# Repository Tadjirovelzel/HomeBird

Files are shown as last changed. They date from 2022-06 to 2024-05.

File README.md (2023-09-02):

The project NestWacht in collaboration with the TU Delft and other benefactors aims to design a sensor station in the form of a birdhouse that uses a camera and weather sensors to document bird activity and monitor properties of the local atmosphere such as humidity, pressure and particulate matter levels. 
This file serves to outline the structure and purpose of the folders contained within the project.

# Project Structure
The essential project structure is displayed below:

    -Code
        -arduino_firmware
        -esp_firmware
        -test_camera
        -test_video
        -legacy_code
    -Enclosure
    -Kicad
        -main_board
        -camera_board
        -gerbers

    The project also contains the complete material bill and the login information for the Node Developer platform.
    Some irrelevant and older development code is stored in the legacy_code folder. 

The electronical components were initally designed by Maarten van Schagen and Quinten Luyten. Tadjiro Velzel further implemented the design and attempted to correct inital mistakes.
The programming necessary to ensure correct and smooth operation of the board and the server was done by Lennard Duynkerke.
The enclosure of the electronics was designed by Thomas van Leeuwen.
The project was overseen and managed by Marit Bogert and Teun Verkerk.

# Hardware
The main board contains the following components, split into sections.

    Power systems section:
        - Three battery connector footprints that lead to battery holders containing three 16650 LiOn batteries
        - Three TP4056 battery charger modules
        - A Solar charger footprint leading to a solar panel
        - A boost converter that regulates the battery power to 5V
        - A Diode to route solar power directly to the boost converter
        - A Diode to regulate the arduino's ability to turn off the boost converter, thus turning off the Esp32 and particulate matter sensor
        - A power FET which turns off the Esp32 and Particulate matter sensor
        - Resistors to regulate the power throughput towards the FET

    Computative section:
        - An Arduino Every that drives the power towards the ESP32 and operates the sensors and an SD card to store sensor data.
        - A LilyGo ESP32 development board

    Sensoric section:
        - Two BME280 breakout boards to monitor air pressure, humidity and temperature both within the birdhouse and towards the outside air
        - A PMS5003 particulate matter sensor

    Data transfer:
        - A Sim LTE module (LilyGo SIM7600E) for data transfer
        - An LTE antenna to transfer data over LTE
        - A Sim-card to route information accross the internet
        - An SD card that stores the sensor data before sending it

The Camera Board contains the following components:

    - An OV2640 camera operating within the visible and infrared spectra 
    - A 24 pin camera connector, soldered to the board
    - A network of capacitors to smooth the voltages of the camera connector and voltage regulators
    - A 2.8V and 1.2V voltage regulator to supply the camera
    - A system of resistors to preload the camera
    - A motion sensor to detect bird activity and trigger the camera
    - Four infrared LEDs to light up for pictures at night, which the birds cannot sense
    - A larger resistor to regulate current to the infrared LEDs

To contain the electronics mentioned above, a plastic enclosure made, printed in PETG by 3d-printer. The design files for this are available in the enclosure folder.

# Software
The software is split in two parts: `arduino_firmware` and `esp_firmware`. The former is designed for the Arduino Every, the main computational unit which is always powered on and operates sensors, sd card, and power to the ESP32. The latter is ran on the LilyGo ESP32 and is used to communicate with the outer world over a 4G connection, as well as to take pictures with the OV2640 camera. Two test files are added in order to test a specific part of the software, `test_camera` to test the camera either over WiFi or over 4G and `test_video` to record an .avi video by sticking individual .jpg files together. For a more detailed description of the software one is directed to the headers of the individual .cpp files.

# Problems
Currently the project contains the following issues:
* Sim module will not send large pictures
* Camera init and capture is inconsistent, bound to inconsistency of the camera connector
* Pin assignment in code does not correspond to PCB design files: PCB files are incorrect and can never work: pin assignment in software is correct.
* Complete integration was never tested
* Likely complete system is too power intensive to drive by solar panel. (Also never tested fully)

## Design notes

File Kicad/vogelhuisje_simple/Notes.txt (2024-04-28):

Useful voltage regulator:
https://www.ti.com/lit/ds/symlink/lm3940.pdf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

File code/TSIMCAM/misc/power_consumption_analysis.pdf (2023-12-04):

### GPS: every 60 seconds, API: 1 point per payload

| mcu - simple delay module - on | mcu - sleep module - on | mcu - deep sleep module - on | mcu - simple delay module - low power mode | mcu - simple delay module - off
Power (mWh) | 286 | 196 | 187 | 298 | 530
Time (s) | 2110s | 1674s | 1544s | 1932s | 3453s
# GPS Points | 34 | 27 | 25 | 32 | 44

# API Posts | 34 | 27 | 25 | 32 | 44

Power (mWh) per hour | 487.962085308057 | 421.505376344086 | 436.010362694301 | 555.27950310559 | 552.562988705474
Power (mWh) per day | 11711.0900473934 | 10116.1290322581 | 10464.2487046632 | 13326.7080745342 | 13261.5117289314
Seconds Per GPS Point | 62s 59ms | 62s | 61s 760ms | 60s 375ms | 78s 477ms
Seconds Per Post | 62s 59ms | 62s | 61s 760ms | 60s 375ms | 78s 477ms
gps_refresh_period (ms) | 60000 | 60000 | 60000 | 60000 | 60000 | 60000 | 60000
api_num_gps_points_in_payload | 1 | 1 | 1 | 1 | 1 | 1 | 1
First Point in API | 03/11/2023 4:01:58 PM | 03/11/2023 4:39:57 PM | 03/11/2023 5:11:57 PM | 03/11/2023 5:41:22 PM | 03/11/2023 2:59:59 PM
Last Point in API | 03/11/2023 4:37:08 PM | 03/11/2023 5:07:51 PM | 03/11/2023 5:37:41 PM | 03/11/2023 6:13:34 PM | 03/11/2023 3:57:32 PM
| 2110s | 1674s | 1544s | 1932s | 3453s | 0 | 0

### GPS: 1min vs 10min per point, API: 1 point per payload

| mcu - simple delay module - on every 1min | mcu - simple delay module - on every 10min | mcu - simple delay module - low power mode every 1min | mcu - simple delay module - low power mode every 10min | mcu - simple delay module - off every 1min | mcu - simple delay module - off every 10min
Power (mWh) | 286 | 1586 | 298 | 2786 | 530 | 944
Time (s) | 2110s | 16309s | 1932s | 29021s | 3453s | 19957s
# GPS Points | 34 | 28 | 32 | 42 | 44 | 33

# API Posts | 34 | 28 | 32 | 42 | 44 | 33

Power (mWh) per hour | 487.962085308057 | 350.088907964927 | 555.27950310559 | 345.59801523035 | 552.562988705474 | 170.286115147567
Power (mWh) per day | 11711.0900473934 | 8402.13379115825 | 13326.7080745342 | 8294.3523655284 | 13261.5117289314 | 4086.86676354161
Seconds Per GPS Point | 62s 59ms | 582s 464ms | 60s 375ms | 690s 976ms | 78s 477ms | 604s 758ms
Seconds Per Post | 62s 59ms | 582s 464ms | 60s 375ms | 690s 976ms | 78s 477ms | 604s 758ms
gps_refresh_period (ms) | 60000 | 600000 | 60000 | 600000 | 60000 | 600000
api_num_gps_points_in_payload | 1 | 1 | 1 | 1 | 1 | 1
First Point in API | 03/11/2023 4:01:58 PM | 03/11/2023 6:32:56 PM | 03/11/2023 5:41:22 PM | 03/11/2023 11:09:26 PM | 03/11/2023 2:59:59 PM | 03/12/2023 7:16:28 AM
Last Point in API | 03/11/2023 4:37:08 PM | 03/11/2023 11:04:45 PM | 03/11/2023 6:13:34 PM | 03/12/2023 7:13:07 AM | 03/11/2023 3:57:32 PM | 03/12/2023 12:49:05 PM
| 2110s | 16309s | 1932s | 29021s | 3453s | 19957s

### GPS: 1min vs 10min per point, API: 1 point per payload

| mcu - deep sleep module - off every 1s | mcu - deep sleep module - off every 10min | mcu - deep sleep module - off every 20min | mcu - deep sleep module - off every 30min | mcu - deep sleep module - off every 40min | mcu - deep sleep module - off every 50min | mcu - deep sleep module - off every 60min
Power (mWh) | 173 | 346 | 560 | 298 | 367 | 530 | 1020
Time (s) | 949s | 10652s | 22382s | 0 | 17235s | 0 | 58249s
# GPS Points | 14 | 18 | 19 | 32 | 8 | 44 | 17

# API Posts | 14 | 18 | 19 | 32 | 8 | 44 | 17

Power (mWh) per hour | 656.269757639621 | 116.935786706722 | 90.0723795907426 | | 76.6579634464752 | | 63.0397088362032
Power (mWh) per day | 15750.4741833509 | 2806.45888096133 | 2161.73711017782 | | 1839.7911227154 | | 1512.95301206888
Seconds Per GPS Point | 73s | 626s 588ms | 1243s 444ms | 0 | 2462s 143ms | 0 | 3640s 563ms
Seconds Per Post | 73s | 626s 588ms | 1243s 444ms | 0 | 2462s 143ms | 0 | 3640s 563ms
Power (mWh) per point | 12.3571428571429 | 19.2222222222222 | 29.4736842105263 | 9.3125 | 45.875 | 12.0454545454545 | 60
gps_refresh_period (ms) | 1000 | 600000 | 1200000 | 180000 | 2400000 | 300000 | 3600000
api_num_gps_points_in_payload | 1 | 1 | 1 | 1 | 1 | 1 | 1
First Point in API | 03/14/2023 7:23:09 PM | 03/13/2023 2:20:58 PM | 03/13/2023 8:00:48 AM | | 03/14/2023 9:37:40 AM | | 03/13/2023 5:22:30 PM
Last Point in API | 03/14/2023 7:38:58 PM | 03/13/2023 5:18:30 PM | 03/13/2023 2:13:50 PM | | 03/14/2023 2:24:55 PM | | 03/14/2023 9:33:19 AM
| 949s | 10652s | 22382s | 0 | 17235s | 0 | 58249s
Notes | This is about as fast as the module can turn on and off. The MCU is not sleeping because the pre-nap and post-nap values are larger than the 1 second. | | | | | | This is heading towards the board limit of 0.0107A x 5.088V = 54.4mWh. The 0.0107A draw is when the module is off and the mcu is in deep sleep.

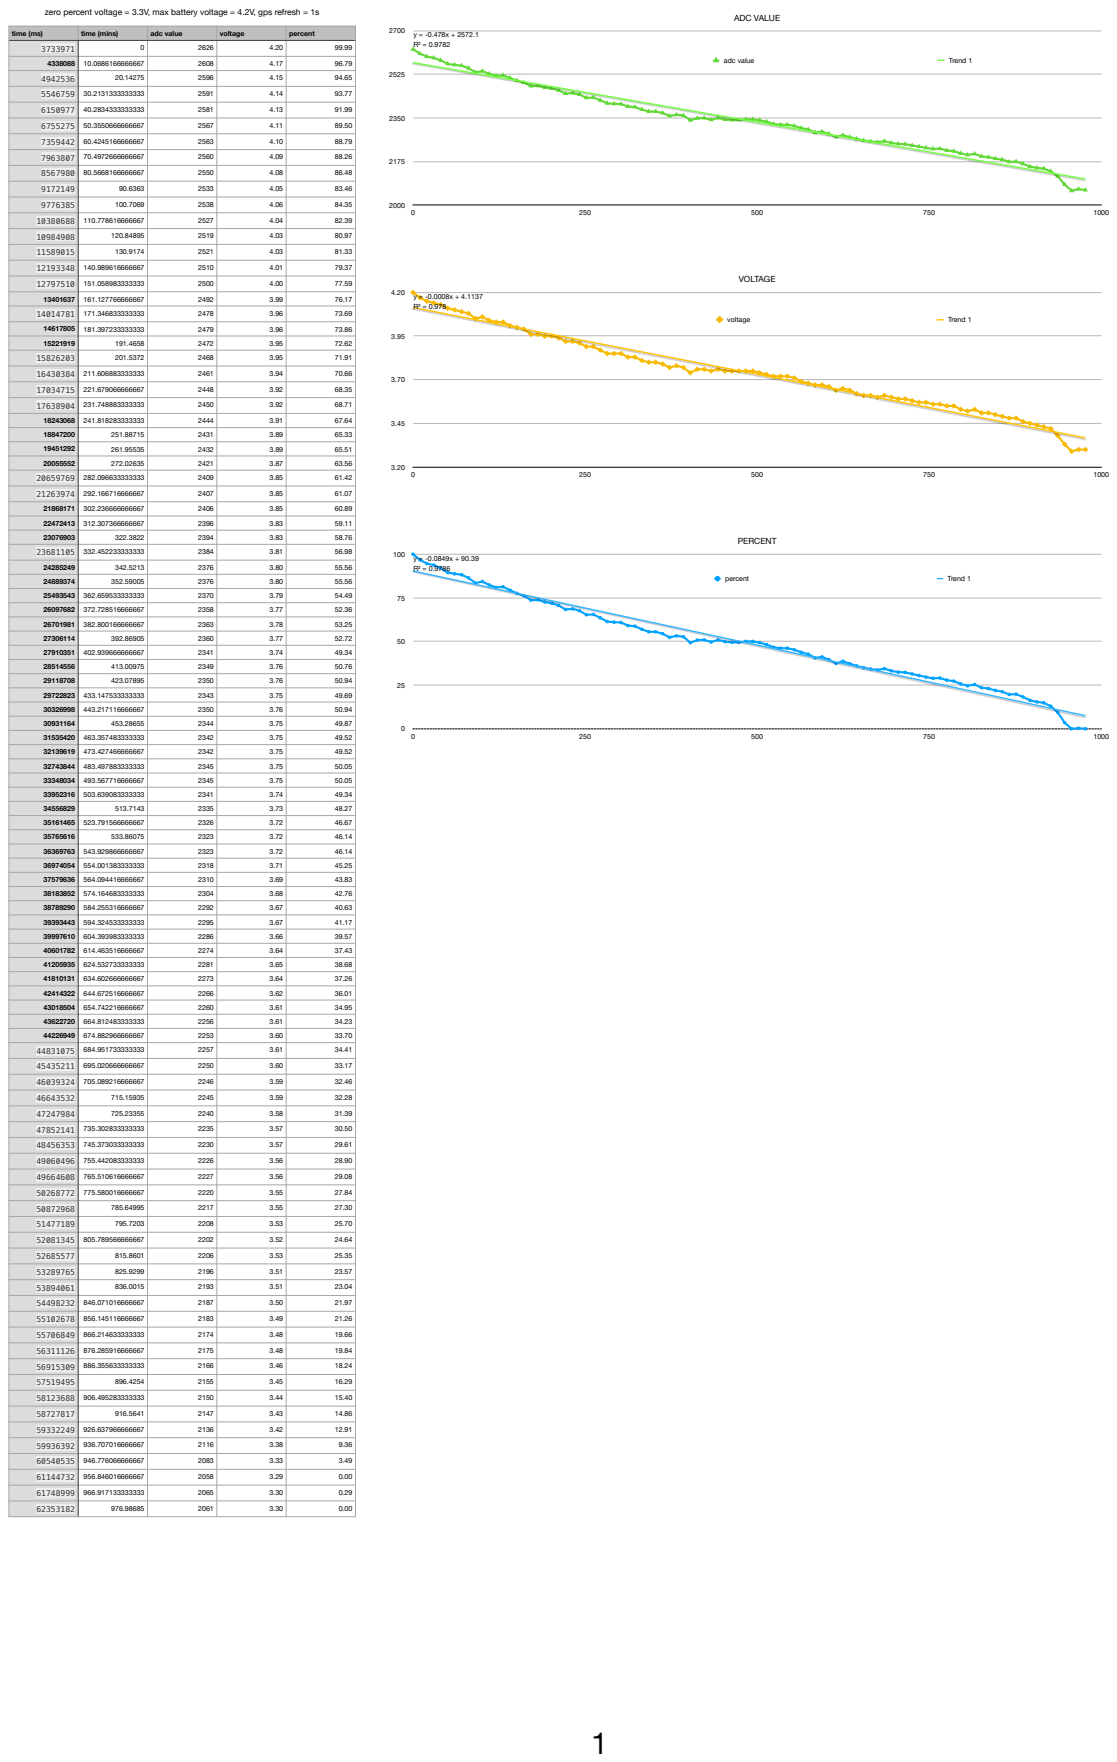
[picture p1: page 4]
PERCENT; percent; Trend 1; ADC VALUE; adc value; VOLTAGE; voltage

zero percent voltage = 3.3V, max battery voltage = 4.2V, gps refresh = 1s

time (ms) | time (mins) | adc value | voltage | percent

4338088 | 10.0686166666667 | 2608 | 4.17 | 96.79
4942536 | 20.14275 | 2596 | 4.15 | 94.65

13401637 | 161.127766666667 | 2492 | 3.99 | 76.17
14014781 | 171.346833333333 | 2478 | 3.96 | 73.69

14617805 | 181.397233333333 | 2479 | 3.96 | 73.86
15221919 | 191.4658 | 2472 | 3.95 | 72.62
15826203 | 201.5372 | 2468 | 3.95 | 71.91

18243068 | 241.818283333333 | 2444 | 3.91 | 67.64
18847200 | 251.88715 | 2431 | 3.89 | 65.33
19451292 | 261.95535 | 2432 | 3.89 | 65.51
20055552 | 272.02635 | 2421 | 3.87 | 63.56
20659769 | 282.096633333333 | 2409 | 3.85 | 61.42

21868171 | 302.236666666667 | 2406 | 3.85 | 60.89
22472413 | 312.307366666667 | 2396 | 3.83 | 59.11
23076903 | 322.3822 | 2394 | 3.83 | 58.76
23681105 | 332.452233333333 | 2384 | 3.81 | 56.98

24285249 | 342.5213 | 2376 | 3.80 | 55.56
24889374 | 352.59005 | 2376 | 3.80 | 55.56
25493543 | 362.659533333333 | 2370 | 3.79 | 54.49
26097682 | 372.728516666667 | 2358 | 3.77 | 52.36
26701981 | 382.800166666667 | 2363 | 3.78 | 53.25
27306114 | 392.86905 | 2360 | 3.77 | 52.72
27910351 | 402.939666666667 | 2341 | 3.74 | 49.34
28514556 | 413.00975 | 2349 | 3.76 | 50.76
29118708 | 423.07895 | 2350 | 3.76 | 50.94
29722823 | 433.147533333333 | 2343 | 3.75 | 49.69
30326998 | 443.217116666667 | 2350 | 3.76 | 50.94
30931164 | 453.28655 | 2344 | 3.75 | 49.87
31535420 | 463.357483333333 | 2342 | 3.75 | 49.52
32139619 | 473.427466666667 | 2342 | 3.75 | 49.52
32743844 | 483.497883333333 | 2345 | 3.75 | 50.05
33348034 | 493.567716666667 | 2345 | 3.75 | 50.05
33952316 | 503.639083333333 | 2341 | 3.74 | 49.34
34556829 | 513.7143 | 2335 | 3.73 | 48.27
35161465 | 523.791566666667 | 2326 | 3.72 | 46.67
35765616 | 533.86075 | 2323 | 3.72 | 46.14
36369763 | 543.929866666667 | 2323 | 3.72 | 46.14
36974054 | 554.001383333333 | 2318 | 3.71 | 45.25
37579636 | 564.094416666667 | 2310 | 3.69 | 43.83
38183852 | 574.164683333333 | 2304 | 3.68 | 42.76
38789290 | 584.255316666667 | 2292 | 3.67 | 40.63
39393443 | 594.324533333333 | 2295 | 3.67 | 41.17
39997610 | 604.393983333333 | 2286 | 3.66 | 39.57
40601782 | 614.463516666667 | 2274 | 3.64 | 37.43
41205935 | 624.532733333333 | 2281 | 3.65 | 38.68
41810131 | 634.602666666667 | 2273 | 3.64 | 37.26
42414322 | 644.672516666667 | 2266 | 3.62 | 36.01
43018504 | 654.742216666667 | 2260 | 3.61 | 34.95
43622720 | 664.812483333333 | 2256 | 3.61 | 34.23
44226949 | 674.882966666667 | 2253 | 3.60 | 33.70
44831075 | 684.951733333333 | 2257 | 3.61 | 34.41

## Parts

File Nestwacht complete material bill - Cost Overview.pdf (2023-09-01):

Camera Board: | Quantity per unit Piece Cost | Per Unit Cost | Binnen? | Hoeveel?
100nF capacitor | 3 | 0.1 | 0.3 https://nl.mouser.com/ProductDetail/Vishay-BC-Components/A104K15X7RF5TAA?qs=Rhhypz%252BI04hkFcAFouRQRA%3D%3D
15pF capacitor | 1 | 0.2 | 0.2 https://nl.mouser.com/ProductDetail/Vishay-BC-Components/A150J15C0GH5TAA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
10uF capacitor | 3 | 0.4 | 1.2 https://nl.mouser.com/ProductDetail/KEMET/C430C106K3R5TA?qs=QTajy0ParP4Iyid6Jgh%2FcQ%3D%3D
2.8V regulator | 1 | 0.42 | 0.42 https://nl.mouser.com/ProductDetail/Microchip-Technology-Atmel/MCP1700-2802E-TO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
1.2V regulator | 1 | 0.42 | 0.42 https://nl.mouser.com/ProductDetail/Microchip-Technology/MCP1700-1202E-TO?qs=h7tZ5KkzNMNzE5IK66v51w%3D%3D
PIR602 motion sensor | 1 | 2.25 | 2.25 https://www.hobbyelectronica.nl/product/mh-sr602-pir-motion-sensor/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 Ja | 29 nog in doos
Nmos transistor | 1 | 0.375 | 0.375 https://nl.mouser.com/ProductDetail/onsemi-Fairchild/BS270-D74Z?qs=0lQeLiL1qyYw667jOLnhoQ%3D%3D
Resistor 100kOhm | 1 | 0.03 | 0.03 https://nl.mouser.com/ProductDetail/Xicon/299-100K-RC?qs=SgDQ6sWmK2MAtrhrA%252BEDMA%3D%3D
Resistor 1kOhm | 1 | 0.03 | 0.03 https://nl.mouser.com/ProductDetail/Xicon/299-1K-RC?qs=sGAEpiMZZMsPqMdJzcrNwoKr2H6yLupXds5lHogE02A%3D
Resistor 33Ohm | 1 | 0.3 | 0.3 https://nl.mouser.com/ProductDetail/Vishay-Beyschlag/MBB0207VC3309FC100?qs=x28CZqCRqykpaohpI5DP0A%3D%3D
InfraRed LEDs | 4 | 0.3 | 1.2 https://nl.mouser.com/ProductDetail/ams-OSRAM/SFH-4253-Z?qs=nTDll3UaDK45QqqnXBr7UQ%3D%3D Ja | 200 stuks
OV2640 camera (850nm, 75mm) | 1 | 3.61 | 3.61 https://nl.aliexpress.com/item/1005003434798242.html Ja | 35 vers in een zakkie
Camera connector | 1 | 0.1 | 0.1 https://lcsc.com/product-detail/FFC-FPC-Connectors_JUSHUO-AFC07-S24ECC-00_C11092.html
Main Board: | Quantity per unit
Arduino Nano (atmega328) | 1 | 3.06 | 3.06 https://nl.aliexpress.com/item/1005002966043359.html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 Ja | 31 nog in doos
ESP32-LilyGo-T_PCIE | 1 | 12.87 | 12.87 https://nl.aliexpress.com/item/4001142716386.html Ja | 30 nog in doos
PCIE0SIM7600E | 1 | 48.63 | 48.63 https://nl.aliexpress.com/item/4001142716386.html Ja | 29 nog in doos
PM Sensor | 1 | 15.87 | 15.87 https://nl.aliexpress.com/item/32944660534.html Ja | 33 nog in doos
SD Reader | 1 | 0.39 | 0.39 https://nl.aliexpress.com/item/1005003932853834.html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 Ja
Pressure sensor 3.3V | 2 | 3.52 | 7.04 https://nl.aliexpress.com/item/32862421810.html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 Nee | Retour afzender door PostNL | Nieuw besteld (500-ish euro) = geleverd
Boost converter | 1 | 0.38 | 0.38 https://nl.aliexpress.com/item/1005002234592016.html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 Ja | 29 nog in zak
Battery Charger Module type C | 3 | 0.66 | 1.98 https://nl.aliexpress.com/item/32649780468.html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 Ja | 76 gevonden
Schottky Diode | 1 | 0.372 | 0.372 https://nl.mouser.com/ProductDetail/STMicroelectronics/1N5817?qs=JV7lzlMm3yKNnxZdh%252BSMnw%3D%3D
General purpose Diode | 1 | 0.69 | 0.69 https://nl.mouser.com/ProductDetail/onsemi-Fairchild/1N4148-T26A?qs=0lQeLiL1qyYizhTuyPCCiA%3D%3D
Power Fet | 1 | 0.97 | 0.97 https://nl.mouser.com/ProductDetail/Infineon-Technologies/IRF9Z34NPBF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
Resistor 100kOhm | 2 | 0.03 | 0.06 https://nl.mouser.com/ProductDetail/Xicon/299-100K-RC?qs=SgDQ6sWmK2MAtrhrA%252BEDMA%3D%3D
Board wire plugs | 4 | 0.03 | 0.12 https://lcsc.com/product-detail/Wire-To-Board-Wire-To-Wire-Connector_JST-Sales-America-B2B-PH-K-S-LF-SN_C131337.html

Peripherals
Solar panel | 1 | 14.42 | 14.42 https://nl.aliexpress.com/item/1005004673747146.html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 Nee | Geweigerd bij Chinese douane (evt. los nasturen aan deelnemers?)
Battery 18650 | 3 | 13.95 | 41.85 https://www.nkon.nl/rechargeable/li-ion/18650-size/xtar-18650-3500-protected-10a.html Ja
Solar power cable | 1 | 1 | 1 https://nl.aliexpress.com/item/1005004480544156.html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 Is dit de USB-C kabel? 29 USB c kabels in zak
JLCPCB main board | 1 | 0.8 | 0.8 Ask Tadjiro Velzel at tadjiro@velzel.com
JLCPCB camera board | 1 | 0.8 | 0.8 Ask Tadjiro Velzel at tadjiro@velzel.com
Enclosure 3D Filament | 0.4 | 30 | 12 https://www.123-3d.nl/REAL-filament-groen-1-75-mm-PETG-1-kg-DFE02023-i1569-t7390.html Ja
Battery Holder 18650 | 3 | 0.3 | 0.9 https://nl.aliexpress.com/item/4000334958532.html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 Ja

To be determined
Cable between main & camera board

Soldering, assembling cost

SIM Cards | 30 4 120 Ja
Summation | AliExpress per unit
Total cost per unit | 173.737 | 109.25
Cost per 30 | 5212.11

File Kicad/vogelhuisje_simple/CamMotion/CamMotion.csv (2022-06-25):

Source: | /home/maarten/git/HomeBird/vogelhuisje_kicad/vogelhuisje_kicad.kicad_sch
Date: | Sat Jun 25 16:42:39 2022
Tool: | Eeschema (6.0.6)
Generator: | /usr/share/kicad/plugins/bom_csv_grouped_by_value.py
Component Count: | 35
Individual Components:
Item | Qty | Reference(s) | Value | LibPart | Footprint | Datasheet | MANUFACTURER | MAXIMUM_PACKAGE_HEIGHT | PARTREV | STANDARD
 |  | A1 | Arduino_Nano_v3.x | MCU_Module:Arduino_Nano_v3.x | Module:Arduino_Nano | http://www.mouser.com/pdfdocs/Gravitech_Arduino_Nano3_0.pdf
 |  | C1 | 100n | Device:C | Capacitor_SMD:C_0201_0603Metric_Pad0.64x0.40mm_HandSolder | ~
 |  | C2 | 15pF | Device:C | Capacitor_SMD:C_01005_0402Metric_Pad0.57x0.30mm_HandSolder | ~
 |  | C3 | 10u | Device:C | Capacitor_SMD:C_0805_2012Metric_Pad1.18x1.45mm_HandSolder | ~
 |  | C4 | 100n | Device:C | Capacitor_SMD:C_0603_1608Metric_Pad1.08x0.95mm_HandSolder | ~
 |  | C5 | 10u | Device:C | Capacitor_SMD:C_0805_2012Metric_Pad1.18x1.45mm_HandSolder | ~
 |  | C6 | 100n | Device:C | Capacitor_SMD:C_0603_1608Metric_Pad1.08x0.95mm_HandSolder | ~
 |  | C7 | 10u | Device:C | Capacitor_SMD:C_0805_2012Metric_Pad1.18x1.45mm_HandSolder | ~
 |  | D1 | D_Schottky | Device:D_Schottky | Diode_SMD:D_SMB_Handsoldering | ~
 |  | D2 | D | Device:D | Diode_THT:D_5W_P12.70mm_Horizontal | ~
 |  | D4 | LED | Device:LED | LED_footprint:SFH 4253 | ~
 |  | D5 | LED | Device:LED | LED_footprint:SFH 4253 | ~
 |  | D6 | LED | Device:LED | LED_footprint:SFH 4253 | ~
 |  | D7 | LED | Device:LED | LED_footprint:SFH 4253 | ~
 |  | J1 | Conn_01x02_Female | Connector:Conn_01x02_Female | Connector_PinSocket_2.54mm:PinSocket_1x02_P2.54mm_Vertical | ~
 |  | J2 | Conn_01x02 | Connector_Generic:Conn_01x02 | Connector_JST:JST_PH_B2B-PH-K_1x02_P2.00mm_Vertical | ~
 |  | J3 | USB_C_Receptacle_USB2.0 | usbC:USB4125-GF-A-0190_REVA2 | GCT_USB4125-GF-A-0190_REVA2 | https://www.usb.org/sites/default/files/documents/usb_type-c.zip | GCT | 3.16 mm | Rev A2 | Manufacturer Recommendations
 |  | J4 | Camera Connector | Connector:Conn_01x24_Female | Connector_FFC-FPC:Hirose_FH12-24S-0.5SH_1x24-1MP_P0.50mm_Horizontal | ~
 |  | J5 | Conn_01x19_Female | Connector:Conn_01x19_Female |  | ~
 |  | J6 | Conn_01x19_Female | Connector:Conn_01x19_Female |  | ~
 |  | P1 | TP4056breakout | TP4056-breakout:TP4056breakout | Components:TP4056breakout
 |  | P2 | GenericBoostConverter | TP4056-breakout:GenericBoostConverter | Components:GenericBoostConverter
 |  | Q1 | Q_PMOS_GSD | Device:Q_PMOS_GSD | Package_TO_SOT_SMD:SOT-23 | ~
 |  | Q2 | Q_NMOS_DSG | Device:Q_NMOS_DSG | Package_TO_SOT_THT:TO-92L_Inline | ~
 |  | R1 | 1k | Device:R | Resistor_THT:R_Axial_DIN0207_L6.3mm_D2.5mm_P10.16mm_Horizontal | ~
 |  | R2 | 100k | Device:R | Resistor_THT:R_Axial_DIN0207_L6.3mm_D2.5mm_P7.62mm_Horizontal | ~
 |  | R3 | R | Device:R | Resistor_THT:R_Axial_DIN0207_L6.3mm_D2.5mm_P10.16mm_Horizontal | ~
 |  | R4 | R | Device:R | Resistor_THT:R_Axial_DIN0207_L6.3mm_D2.5mm_P10.16mm_Horizontal | ~
 |  | U1 | XC6206-2.8V | Regulator_Linear:XC6206PxxxMR | Package_TO_SOT_SMD:SOT-23 | https://www.torexsemi.com/file/xc6206/XC6206.pdf
 |  | U2 | XC6206-1.2V | Regulator_Linear:XC6206PxxxMR | Package_TO_SOT_SMD:SOT-23 | https://www.torexsemi.com/file/xc6206/XC6206.pdf
 |  | U3 | ESP32-LilyGo-T_PCIE | voglehuisje_sensors_and_ESP:ESP32-LilyGo-T_PCIE | components:Lilygo_T_PCIE
 |  | U4 | PMS5003 | vogelhuisje_kicad-cache:PMS5003 | Connector_PinSocket_2.54mm:PinSocket_1x08_P2.54mm_Vertical
 |  | U5 | SD-card-reader | vogelhuisje_kicad-cache:SD-card-reader | Connector_PinSocket_2.54mm:PinSocket_1x06_P2.54mm_Vertical
 |  | U6 | BME280Breakout | voglehuisje_sensors_and_ESP:BME280Breakout | Connector_PinHeader_2.54mm:PinHeader_1x06_P2.54mm_Vertical
 |  | U7 | BME280Breakout | voglehuisje_sensors_and_ESP:BME280Breakout | Connector_PinHeader_2.54mm:PinHeader_1x06_P2.54mm_Vertical
Collated Components:
Item | Qty | Reference(s) | Value | LibPart | Footprint | Datasheet | MANUFACTURER | MAXIMUM_PACKAGE_HEIGHT | PARTREV | STANDARD
1 | 1 | A1 | Arduino_Nano_v3.x | MCU_Module:Arduino_Nano_v3.x | Module:Arduino_Nano | http://www.mouser.com/pdfdocs/Gravitech_Arduino_Nano3_0.pdf
2 | 1 | C1 | 100n | Device:C | Capacitor_SMD:C_0201_0603Metric_Pad0.64x0.40mm_HandSolder | ~
3 | 1 | C2 | 15pF | Device:C | Capacitor_SMD:C_01005_0402Metric_Pad0.57x0.30mm_HandSolder | ~
4 | 3 | C3, C5, C7 | 10u | Device:C | Capacitor_SMD:C_0805_2012Metric_Pad1.18x1.45mm_HandSolder | ~
5 | 2 | C4, C6 | 100n | Device:C | Capacitor_SMD:C_0603_1608Metric_Pad1.08x0.95mm_HandSolder | ~
6 | 1 | D1 | D_Schottky | Device:D_Schottky | Diode_SMD:D_SMB_Handsoldering | ~
7 | 1 | D2 | D | Device:D | Diode_THT:D_5W_P12.70mm_Horizontal | ~
8 | 4 | D4, D5, D6, D7 | LED | Device:LED | LED_footprint:SFH 4253 | ~
9 | 1 | J1 | Conn_01x02_Female | Connector:Conn_01x02_Female | Connector_PinSocket_2.54mm:PinSocket_1x02_P2.54mm_Vertical | ~
10 | 1 | J2 | Conn_01x02 | Connector_Generic:Conn_01x02 | Connector_JST:JST_PH_B2B-PH-K_1x02_P2.00mm_Vertical | ~
11 | 1 | J3 | USB_C_Receptacle_USB2.0 | usbC:USB4125-GF-A-0190_REVA2 | GCT_USB4125-GF-A-0190_REVA2 | https://www.usb.org/sites/default/files/documents/usb_type-c.zip | GCT | 3.16 mm | Rev A2 | Manufacturer Recommendations
12 | 1 | J4 | Camera Connector | Connector:Conn_01x24_Female | Connector_FFC-FPC:Hirose_FH12-24S-0.5SH_1x24-1MP_P0.50mm_Horizontal | ~
13 | 2 | J5, J6 | Conn_01x19_Female | Connector:Conn_01x19_Female |  | ~
14 | 1 | P1 | TP4056breakout | TP4056-breakout:TP4056breakout | Components:TP4056breakout
15 | 1 | P2 | GenericBoostConverter | TP4056-breakout:GenericBoostConverter | Components:GenericBoostConverter
16 | 1 | Q1 | Q_PMOS_GSD | Device:Q_PMOS_GSD | Package_TO_SOT_SMD:SOT-23 | ~
17 | 1 | Q2 | Q_NMOS_DSG | Device:Q_NMOS_DSG | Package_TO_SOT_THT:TO-92L_Inline | ~
18 | 1 | R1 | 1k | Device:R | Resistor_THT:R_Axial_DIN0207_L6.3mm_D2.5mm_P10.16mm_Horizontal | ~
19 | 1 | R2 | 100k | Device:R | Resistor_THT:R_Axial_DIN0207_L6.3mm_D2.5mm_P7.62mm_Horizontal | ~
20 | 2 | R3, R4 | R | Device:R | Resistor_THT:R_Axial_DIN0207_L6.3mm_D2.5mm_P10.16mm_Horizontal | ~
21 | 1 | U1 | XC6206-2.8V | Regulator_Linear:XC6206PxxxMR | Package_TO_SOT_SMD:SOT-23 | https://www.torexsemi.com/file/xc6206/XC6206.pdf
22 | 1 | U2 | XC6206-1.2V | Regulator_Linear:XC6206PxxxMR | Package_TO_SOT_SMD:SOT-23 | https://www.torexsemi.com/file/xc6206/XC6206.pdf
23 | 1 | U3 | ESP32-LilyGo-T_PCIE | voglehuisje_sensors_and_ESP:ESP32-LilyGo-T_PCIE | components:Lilygo_T_PCIE
24 | 1 | U4 | PMS5003 | vogelhuisje_kicad-cache:PMS5003 | Connector_PinSocket_2.54mm:PinSocket_1x08_P2.54mm_Vertical
25 | 1 | U5 | SD-card-reader | vogelhuisje_kicad-cache:SD-card-reader | Connector_PinSocket_2.54mm:PinSocket_1x06_P2.54mm_Vertical
26 | 2 | U6, U7 | BME280Breakout | voglehuisje_sensors_and_ESP:BME280Breakout | Connector_PinHeader_2.54mm:PinHeader_1x06_P2.54mm_Vertical

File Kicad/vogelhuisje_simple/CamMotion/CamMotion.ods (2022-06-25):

Source: | /home/maarten/git/HomeBird/vogelhuisje_kicad/vogelhuisje_kicad.kicad_sch
Date: | Sun May 29 18:20:35 2022
Tool: | Eeschema (6.0.5)
Generator: | /usr/share/kicad/plugins/bom_csv_grouped_by_value.py
Component Count: | 35
Individual Components:
Item | Qty | Reference(s) | Value | LibPart | Footprint | Datasheet
 |  | A1 | Arduino_Nano_v3.x | MCU_Module:Arduino_Nano_v3.x | Module:Arduino_Nano | http://www.mouser.com/pdfdocs/Gravitech_Arduino_Nano3_0.pdf
 |  | C1 | 100n | Device:C |  | ~
 |  | C2 | 15pF | Device:C |  | ~
 |  | C3 | 10u | Device:C |  | ~
 |  | C4 | 100n | Device:C |  | ~
 |  | C5 | 10u | Device:C |  | ~
 |  | C6 | 100n | Device:C |  | ~
 |  | C7 | 10u | Device:C |  | ~
 |  | D1 | D_Zener | Device:D_Zener | Diode_SMD:D_SMB_Handsoldering | ~
 |  | D2 | D | Device:D |  | ~
 |  | D3 | D | Device:D |  | ~
 |  | D4 | LED | Device:LED |  | ~
 |  | D5 | LED | Device:LED |  | ~
 |  | D6 | LED | Device:LED |  | ~
 |  | D7 | LED | Device:LED |  | ~
 |  | J1 | Conn_01x02_Female | Connector:Conn_01x02_Female | Connector_PinSocket_2.54mm:PinSocket_1x02_P2.54mm_Vertical | ~
 |  | J2 | Conn_01x02 | Connector_Generic:Conn_01x02 | Connector_JST:JST_PH_B2B-PH-K_1x02_P2.00mm_Vertical | ~
 |  | J3 | USB_C_Receptacle_USB2.0 | Connector:USB_C_Receptacle_USB2.0 | Connector_USB:USB_C_Receptacle_HRO_TYPE-C-31-M-12 | https://www.usb.org/sites/default/files/documents/usb_type-c.zip
 |  | J4 | Camera Connector | Connector:Conn_01x26_Female | Connector_FFC-FPC:Hirose_FH12-24S-0.5SH_1x24-1MP_P0.50mm_Horizontal | ~
 |  |  |  |  |  | ~
 |  | P1 | TP4056breakout | TP4056-breakout:TP4056breakout | Components:TP4056breakout
 |  | P2 | GenericBoostConverter | TP4056-breakout:GenericBoostConverter | Components:GenericBoostConverter
 |  | Q1 | Q_PMOS_GSD | Device:Q_PMOS_GSD | Package_TO_SOT_SMD:SOT-23 | ~
 |  | Q2 | Q_NMOS_DSG | Device:Q_NMOS_DSG |  | ~
 |  | R1 | 1k | Device:R |  | ~
 |  | R2 | 100k | Device:R | Resistor_THT:R_Axial_DIN0207_L6.3mm_D2.5mm_P7.62mm_Horizontal | ~
 |  | R3 | R | Device:R |  | ~
 |  | R4 | R | Device:R |  | ~
 |  | U1 | XC6206-2.8V | Regulator_Linear:XC6206PxxxMR | Package_TO_SOT_SMD:SOT-23 | https://www.torexsemi.com/file/xc6206/XC6206.pdf
 |  | U2 | XC6206-1.2V | Regulator_Linear:XC6206PxxxMR | Package_TO_SOT_SMD:SOT-23 | https://www.torexsemi.com/file/xc6206/XC6206.pdf
 |  | U3 | ESP32-LilyGo-T_PCIE | voglehuisje_sensors_and_ESP:ESP32-LilyGo-T_PCIE | Components:Tity-LilyGo
 |  | U4 | PMS5003 | vogelhuisje_kicad-cache:PMS5003
 |  | U5 | SD-card-reader | vogelhuisje_kicad-cache:SD-card-reader
 |  | U6 | BME280Breakout | voglehuisje_sensors_and_ESP:BME280Breakout | Components:Breakout-6
 |  | U7 | BME280Breakout | voglehuisje_sensors_and_ESP:BME280Breakout | Components:Breakout-6
Collated Components:
Item | Qty | Reference(s) | Value | LibPart | Footprint | Datasheet
1 | 1 | A1 | Arduino_Nano_v3.x | MCU_Module:Arduino_Nano_v3.x | Module:Arduino_Nano | http://www.mouser.com/pdfdocs/Gravitech_Arduino_Nano3_0.pdf
2 | 3 | C1, C4, C6 | 100n | Device:C |  | ~
3 | 1 | C2 | 15pF | Device:C |  | ~
4 | 3 | C3, C5, C7 | 10u | Device:C |  | ~
5 | 1 | D1 | D_Schottky | Device:D_Zener | Diode_SMD:D_SMB_Handsoldering | ~
6 | 2 | D2, D3 | D | Device:D |  | ~
7 | 4 | D4, D5, D6, D7 | LED | Device:LED |  | ~
8 | 1 | J1 | Conn_01x02_Female | Connector:Conn_01x02_Female | Connector_PinSocket_2.54mm:PinSocket_1x02_P2.54mm_Vertical | ~
9 | 1 | J2 | Conn_01x02 | Connector_Generic:Conn_01x02 | Connector_JST:JST_PH_B2B-PH-K_1x02_P2.00mm_Vertical | ~
10 | 1 | J3 | USB_C_Receptacle_USB2.0 | Connector:USB_C_Receptacle_USB2.0 | Connector_USB:USB_C_Receptacle_HRO_TYPE-C-31-M-12 | https://www.usb.org/sites/default/files/documents/usb_type-c.zip
11 | 1 | J4 | Camera Connector | Connector:Conn_01x26_Female | Connector_FFC-FPC:Hirose_FH12-24S-0.5SH_1x24-1MP_P0.50mm_Horizontal | ~
12 |  |  |  |  |  | ~
13 | 1 | P1 | TP4056breakout | TP4056-breakout:TP4056breakout | Components:TP4056breakout
14 | 1 | P2 | GenericBoostConverter | TP4056-breakout:GenericBoostConverter | Components:GenericBoostConverter
15 | 1 | Q1 | Q_PMOS_GSD | Device:Q_PMOS_GSD | Package_TO_SOT_SMD:SOT-23 | ~
16 | 1 | Q2 | Q_NMOS_DSG | Device:Q_NMOS_DSG |  | ~
17 | 1 | R1 | 1k | Device:R |  | ~
18 | 1 | R2 | 100k | Device:R | Resistor_THT:R_Axial_DIN0207_L6.3mm_D2.5mm_P7.62mm_Horizontal | ~
19 | 2 | R3, R4 | R | Device:R |  | ~
20 | 1 | U1 | XC6206-2.8V | Regulator_Linear:XC6206PxxxMR | Package_TO_SOT_SMD:SOT-23 | https://www.torexsemi.com/file/xc6206/XC6206.pdf
21 | 1 | U2 | XC6206-1.2V | Regulator_Linear:XC6206PxxxMR | Package_TO_SOT_SMD:SOT-23 | https://www.torexsemi.com/file/xc6206/XC6206.pdf
22 | 1 | U3 | ESP32-LilyGo-T_PCIE | voglehuisje_sensors_and_ESP:ESP32-LilyGo-T_PCIE | Components:Tity-LilyGo
23 | 1 | U4 | PMS5003 | vogelhuisje_kicad-cache:PMS5003
24 | 1 | U5 | SD-card-reader | vogelhuisje_kicad-cache:SD-card-reader
25 | 2 | U6, U7 | BME280Breakout | voglehuisje_sensors_and_ESP:BME280Breakout | Components:Breakout-6
 |  |  | SIM7600E
 |  |  | SD card | ← Bad SD cards
 |  | Not enough | Camera
 |  | In stock
 |  | Not sure about stock, but is ordered
 |  | Van Maarten

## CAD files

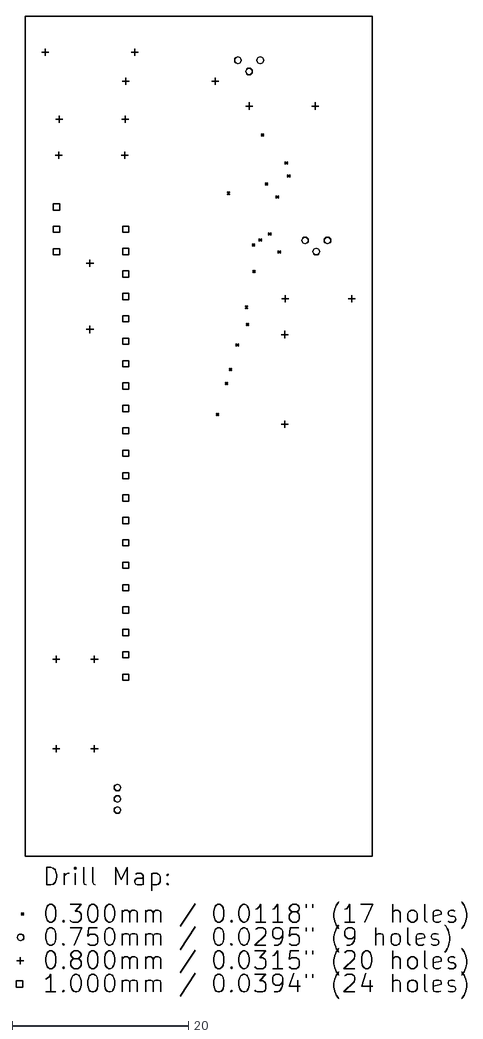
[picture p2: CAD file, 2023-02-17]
Kicad/Gerbers/Cameraboard/new_new/vogelhuisje_camera_board-PTH-drl_map.dxf
51.0 x 111.4

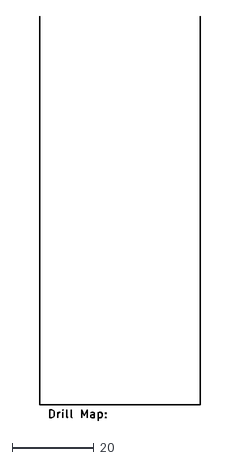
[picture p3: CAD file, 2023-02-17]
Kicad/Gerbers/Cameraboard/new_new/vogelhuisje_camera_board-NPTH-drl_map.dxf
39.4 x 99.1

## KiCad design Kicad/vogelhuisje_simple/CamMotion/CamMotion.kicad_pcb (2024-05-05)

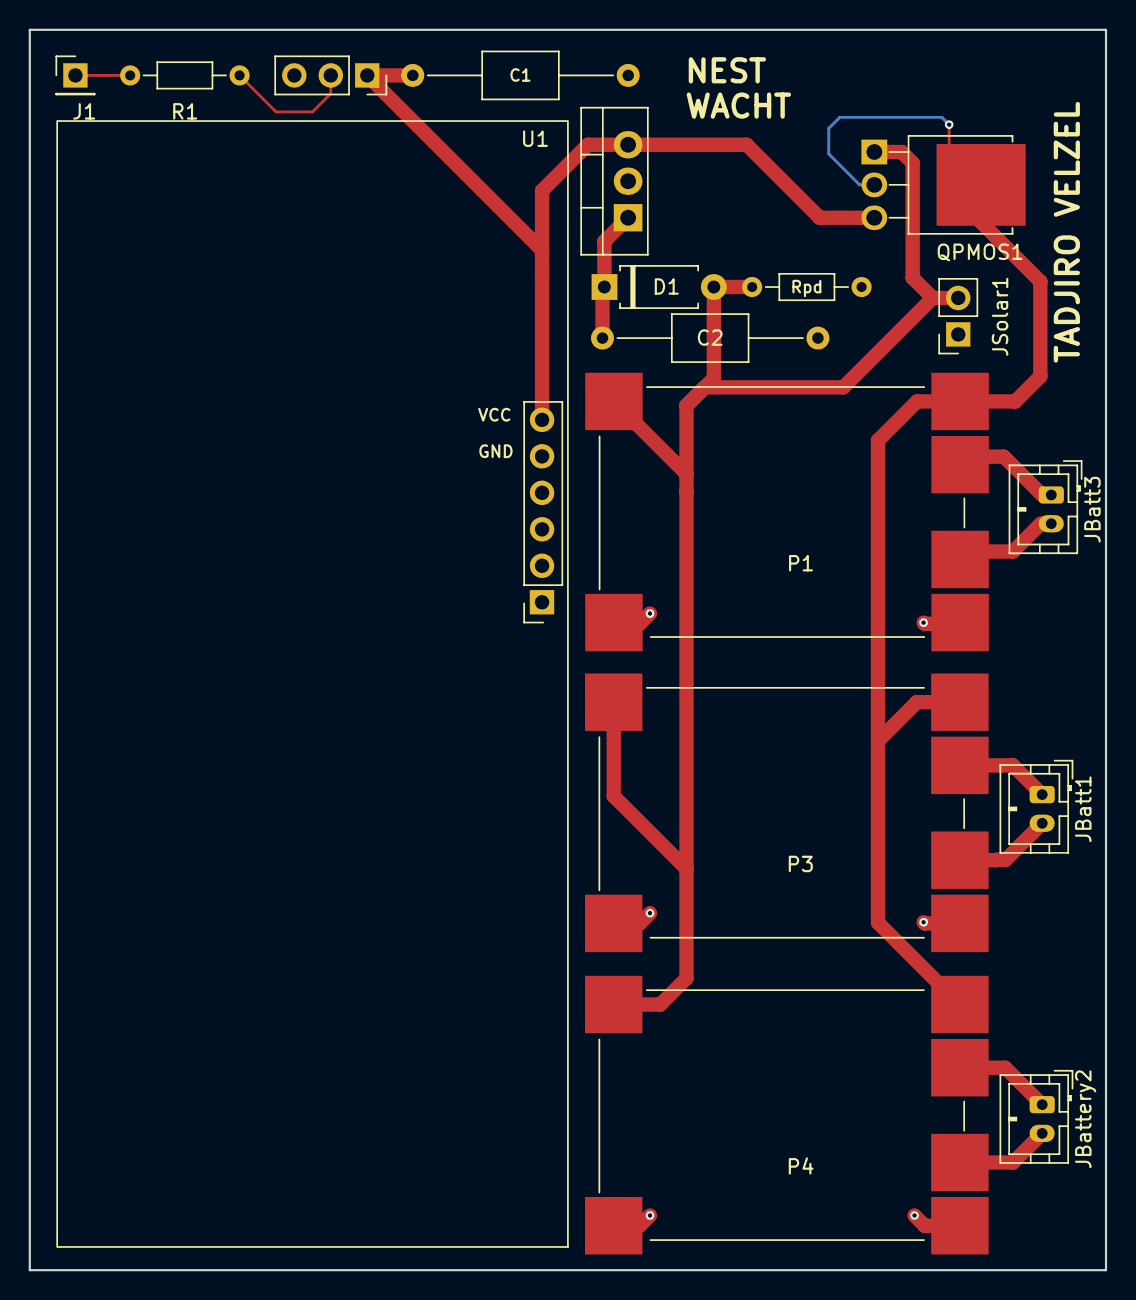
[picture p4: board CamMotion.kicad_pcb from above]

Board: 2 copper layers, 74.9 x 86.4 mm, 17 parts (0 on the bottom side), 13 nets.

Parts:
C1: 100u; C_Axial_L5.1mm_D3.1mm_P15.00mm_Horizontal
C2: 10u; C_Axial_L5.1mm_D3.1mm_P15.00mm_Horizontal
D1: D_Schot; D_A-405_P7.62mm_Horizontal
J1: Conn_01x01_Pin; PinHeader_1x01_P2.54mm_Vertical
JBatt1: Batt3; JST_PH_B2B-PH-K_1x02_P2.00mm_Vertical
JBatt3: Batt1; JST_PH_B2B-PH-K_1x02_P2.00mm_Vertical
JBattery2: JBatt2; JST_PH_B2B-PH-K_1x02_P2.00mm_Vertical
JMotion1: -; PinSocket_1x03_P2.54mm_Vertical
JSolar1: Conn_01x02_Female; PinSocket_1x02_P2.54mm_Vertical
P1, P3, P4: TP4056breakout
QPMOS1: TSM680P06CH
R1: 4.7k; R_Axial_DIN0204_L3.6mm_D1.6mm_P7.62mm_Horizontal
Rpd: 47k; R_Axial_DIN0204_L3.6mm_D1.6mm_P7.62mm_Horizontal
U1: T-simcam; TSimCam
UReg1: LD1117; TO-220-3_Vertical

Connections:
/Power Supply/VSolar: D1.2 (A), JSolar1.2, P1.1 (Vin+), P3.1 (Vin+), P4.1 (Vin+), QPMOS1.1 (G), Rpd.2
/Power Supply/Vbat: P1.3 (OUT+), P3.3 (OUT+), P4.3 (OUT+), QPMOS1.2 (D)
/Sensors and microcontrollers/Motion_out: J1.1, R1.1
GND: C1.2, C2.2, JMotion1.3, JSolar1.1, P1.2 (GND), P1.6 (OUT-), P3.2 (GND), P3.6 (OUT-), P4.2 (GND), P4.6 (OUT-), Rpd.1, U1.5 (Gnd), UReg1.2 (GND)
unnamed: C2.1, D1.1 (K), UReg1.1 (VI)
unnamed: JBatt1.1, P3.4 (B+)
unnamed: JBatt1.2, P3.5 (B-)
unnamed: JBatt3.1, P1.4 (B+)
unnamed: JBatt3.2, P1.5 (B-)
unnamed: JBattery2.1, P4.4 (B+)
unnamed: JBattery2.2, P4.5 (B-)
unnamed: JMotion1.2, R1.2
Vcc: C1.1, JMotion1.1, QPMOS1.3 (S), U1.6 (3V3), UReg1.3 (VO)

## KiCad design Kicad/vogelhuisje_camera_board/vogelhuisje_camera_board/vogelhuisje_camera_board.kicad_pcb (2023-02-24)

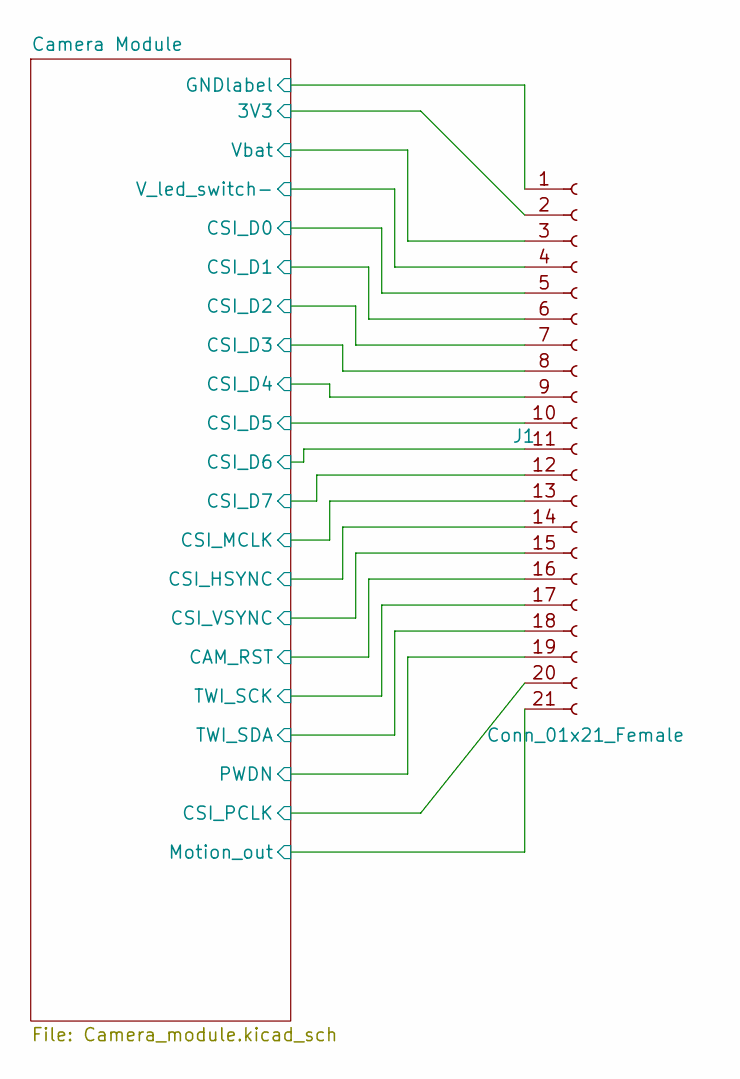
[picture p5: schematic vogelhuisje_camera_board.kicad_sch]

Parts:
J1: Conn_01x21_Female; PinHeader_1x21_P2.54mm_Vertical

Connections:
3V3: J1.2; also elsewhere on the board
/Camera Module/CAM_RST: J1.16; also elsewhere on the board
/Camera Module/CSI_D0: J1.5; also elsewhere on the board
/Camera Module/CSI_D1: J1.6; also elsewhere on the board
/Camera Module/CSI_D2: J1.7; also elsewhere on the board
/Camera Module/CSI_D3: J1.8; also elsewhere on the board
/Camera Module/CSI_D4: J1.9; also elsewhere on the board
/Camera Module/CSI_D5: J1.10; also elsewhere on the board
/Camera Module/CSI_D6: J1.11; also elsewhere on the board
/Camera Module/CSI_D7: J1.12; also elsewhere on the board
/Camera Module/CSI_HSYNC: J1.14; also elsewhere on the board
/Camera Module/CSI_MCLK: J1.13; also elsewhere on the board
/Camera Module/CSI_PCLK: J1.20; also elsewhere on the board
/Camera Module/CSI_VSYNC: J1.15; also elsewhere on the board
/Camera Module/Motion_out: J1.21; also elsewhere on the board
/Camera Module/PWDN: J1.19; also elsewhere on the board
/Camera Module/TWI_SCK: J1.17; also elsewhere on the board
/Camera Module/TWI_SDA: J1.18; also elsewhere on the board
/Camera Module/V_led_switch-: J1.4; also elsewhere on the board
/Camera Module/Vbat: J1.3; also elsewhere on the board
GND: J1.1; also elsewhere on the board

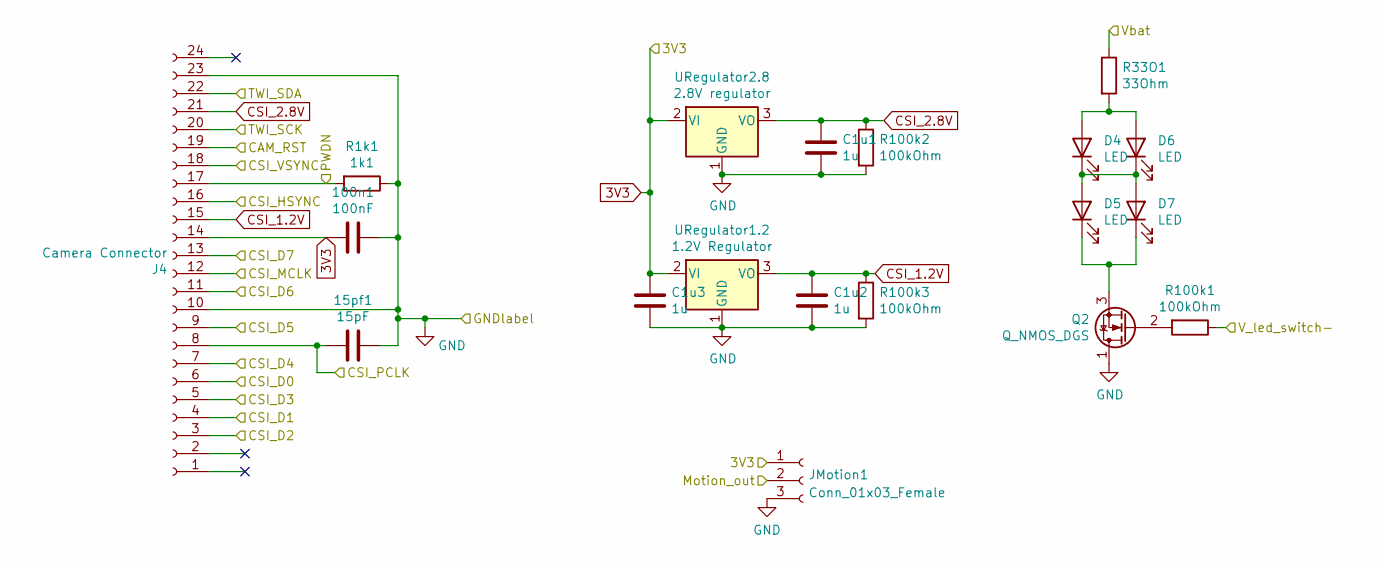
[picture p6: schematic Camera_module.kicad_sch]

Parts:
15pf1: 15pF; C_Axial_L5.1mm_D3.1mm_P7.50mm_Horizontal
100n1: 100nF; C_Axial_L5.1mm_D3.1mm_P7.50mm_Horizontal
C1u1, C1u2, C1u3: 1u; C_Axial_L5.1mm_D3.1mm_P7.50mm_Horizontal
D4, D5, D6, D7: LED; SFH 4253
J4: Camera Connector; CONN_MOLEX_52437-2471
JMotion1: Conn_01x03_Female; PinHeader_1x03_P2.54mm_Vertical
Q2: Q_NMOS_DGS; TO-92L_Inline
R1k1: 1k1; R_Axial_DIN0207_L6.3mm_D2.5mm_P10.16mm_Horizontal
R33O1: 33Ohm; R_Axial_DIN0207_L6.3mm_D2.5mm_P10.16mm_Horizontal
R100k1, R100k2, R100k3: 100kOhm; R_Axial_DIN0207_L6.3mm_D2.5mm_P10.16mm_Horizontal
URegulator1.2: 1.2V Regulator; TO-92
URegulator2.8: 2.8V regulator; TO-92

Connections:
3V3: 100n1.2, C1u3.1, J4.14, JMotion1.1, URegulator1.2.2 (VI), URegulator2.8.2 (VI); also elsewhere on the board
/Camera Module/CAM_RST: J4.19; also elsewhere on the board
/Camera Module/CSI_D0: J4.6; also elsewhere on the board
/Camera Module/CSI_D1: J4.4; also elsewhere on the board
/Camera Module/CSI_D2: J4.3; also elsewhere on the board
/Camera Module/CSI_D3: J4.5; also elsewhere on the board
/Camera Module/CSI_D4: J4.7; also elsewhere on the board
/Camera Module/CSI_D5: J4.9; also elsewhere on the board
/Camera Module/CSI_D6: J4.11; also elsewhere on the board
/Camera Module/CSI_D7: J4.13; also elsewhere on the board
/Camera Module/CSI_HSYNC: J4.16; also elsewhere on the board
/Camera Module/CSI_MCLK: J4.12; also elsewhere on the board
/Camera Module/CSI_PCLK: 15pf1.2, J4.8; also elsewhere on the board
/Camera Module/CSI_VSYNC: J4.18; also elsewhere on the board
/Camera Module/Motion_out: JMotion1.2; also elsewhere on the board
/Camera Module/PWDN: J4.17, R1k1.2; also elsewhere on the board
/Camera Module/TWI_SCK: J4.20; also elsewhere on the board
/Camera Module/TWI_SDA: J4.22; also elsewhere on the board
/Camera Module/V_led_switch-: R100k1.1; also elsewhere on the board
/Camera Module/Vbat: R33O1.1; also elsewhere on the board
CSI_1.2V: C1u2.1, J4.15, R100k3.1, URegulator1.2.3 (VO)
CSI_2.8V: C1u1.1, J4.21, R100k2.1, URegulator2.8.3 (VO)
GND: 15pf1.1, 100n1.1, C1u1.2, C1u2.2, C1u3.2, J4.10, J4.23, JMotion1.3, Q2.1 (D), R1k1.1, R100k2.2, R100k3.2, URegulator1.2.1 (GND), URegulator2.8.1 (GND); also elsewhere on the board
unnamed: D4.1 (K), D5.2 (A), D6.1 (K), D7.2 (A)
unnamed: D4.2 (A), D6.2 (A), R33O1.2
unnamed: D5.1 (K), D7.1 (K), Q2.3 (S)
unnamed: Q2.2 (G), R100k1.2

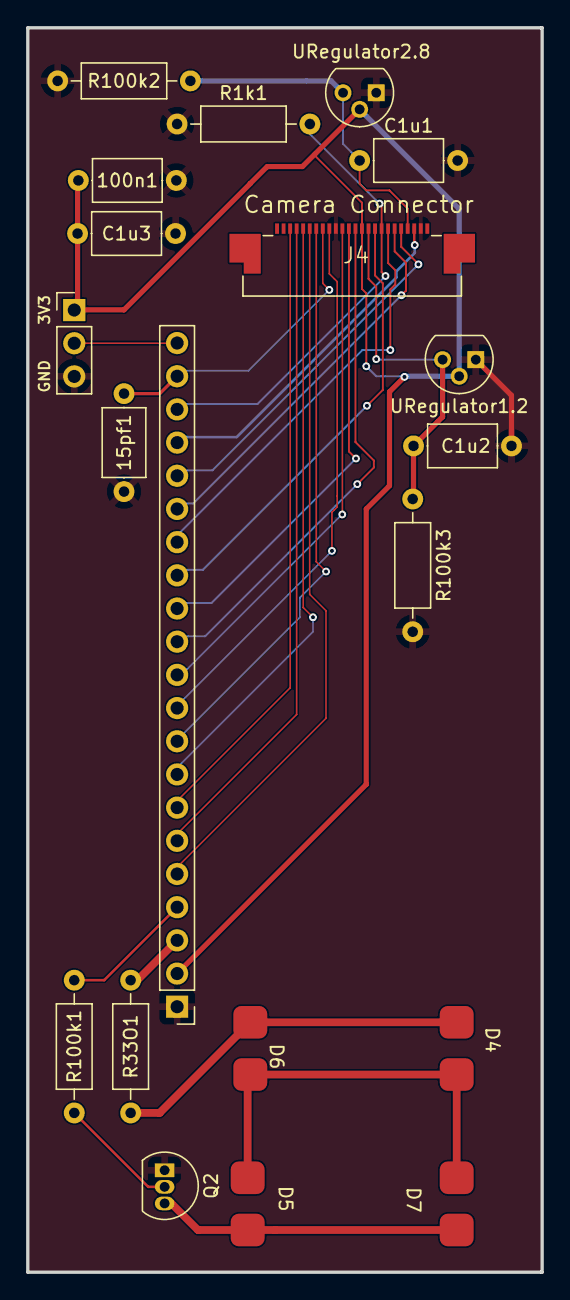
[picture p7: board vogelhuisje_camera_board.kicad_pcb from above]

Board: 2 copper layers, 39.4 x 95.2 mm, 20 parts (0 on the bottom side), 27 nets.

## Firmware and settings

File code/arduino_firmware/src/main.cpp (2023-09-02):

/* arduino_firmware/src/main.cpp   -   Main code designed to run on the Arduino Nano Every

  All sensors are connected to the Nano, and sensor data is stored on a SD card. The Nano every also controls whether or not the ESP32 is powered on.
  This code is built as a state machine, with the states defined first and the transitions between different states second. Six different states are defined:
    -s0_sleep() is the ground state and consists of a 1024 ms sleep;
    -s1_measure_BME() is called to read out pressure, temperature, humidity of the BME280 sensors;
    -s2_measure_PMS() is called to read out air quality of the PMS5003 sensor;
    -s3_send() is the state used to communicate sensor data to the ERSP32;
    -s4_time() is used to obtain the current time from the ESP32;
    -s5_picture() calls the ESP32 to take a picture;
    -s6_video() calls the ESP32 to take a video;

  After any state with a connection to the ESP32 (i.e. internet connection), state S4 is called to obtain the current time. After any other state a 
  transition is made to ground state S0 in order to put the Nano Every in sleep mode and save power.
  
  The use of delay() is minimized throughout the code, sleep_cpu() is used instead in order to save power.

*/

#include <Arduino.h>
#include <avr/sleep.h>

#include "Wire.h"
#include "SPI.h"
#include "SD.h"

#include <PMserial.h> 
#include <StateMachine.h>
#include <BlueDot_BME280.h>
#include <ArduinoJson.h>

#define INTERRUPT_OUTPUT_PIN 4
#define PMS_TX 8
#define PMS_RX 9
#define PIR_PIN 2

#define test_mode

#ifdef test_mode
  #define pms_interval 50000
  #define bme_interval 20000
  #define send_interval 120000
  #define pic_interval 20000
  #define cooldown 240000
#else
  #define pms_interval 1800000
  #define bme_interval 300000
  #define send_interval 3600000
  #define pic_interval 300000
  #define cooldown 108000000
#endif

// Functions
void s0_sleep();
void s1_measure_BME();
void s2_measure_PMS();
void s3_send();
void s4_time();
void s5_picture();
void s6_video();
void write_to_file(StaticJsonDocument<256> document, String filename);
void message_to_esp(String message_string);
void sleep(int sleep_time);
bool sleep_while(int sleep_time);

StateMachine machine = StateMachine();

// Define states
State* S0 = machine.addState(&s0_sleep); 
State* S1 = machine.addState(&s1_measure_BME); 
State* S2 = machine.addState(&s2_measure_PMS); 
State* S3 = machine.addState(&s3_send); 
State* S4 = machine.addState(&s4_time); 
State* S5 = machine.addState(&s5_picture); 
State* S6 = machine.addState(&s6_video); 

// PMS5003 Pins and serial connection
SerialPM pms(PMS5003, PMS_RX, PMS_TX);
bool pms_value_updated = false;

// BME280 objects
BlueDot_BME280 bme1;                                     
BlueDot_BME280 bme2;                                     

// Time variables
unsigned long myTimer = 0;
unsigned long timer_last = 0;
unsigned long pms_last = 0;
unsigned long bme_last = 0;
unsigned long send_last = 0;
unsigned long picture_last = 0;
unsigned long video_last = 0;
unsigned long time_last = 0;
unsigned long unix_time = 0;

// Time function
unsigned long currentTime()
{
  unsigned long current_time = myTimer + (millis() - timer_last);
  return current_time;
}

// Sleep functions
void RTC_init(void)
{
  while (RTC.STATUS > 0) ;     //Wait for all register to be synchronized 
 
  RTC.CLKSEL = RTC_CLKSEL_INT1K_gc;        // Run low power oscillator (OSCULP32K) at 1024Hz for long term sleep
  RTC.PITINTCTRL = RTC_PI_bm;              // PIT Interrupt: enabled 

  RTC.PITCTRLA = RTC_PERIOD_CYC1024_gc | RTC_PITEN_bm;     // Set period 8 seconds (8192 for eight sec) and enable PIC                      
}

ISR(RTC_PIT_vect)
{
  RTC.PITINTFLAGS = RTC_PI_bm;          // Clear interrupt flag by writing '1' (required) 
}


//======================================//
//=============== States ===============//
//======================================//


void s0_sleep()
{
  myTimer += (millis() - timer_last);
  sleep_cpu();
  myTimer += 1024;
  timer_last = millis();
  message_to_esp("Arduino just woke up; millis() = " + String(millis()) + "; time (ms) = " + String(currentTime()));
}

void s1_measure_BME()
{
  // Create json object
  StaticJsonDocument<256> doc;

  // Read pms values
  if(bme1.init() == 0x60)
  {
    doc["temperature1"] = bme1.readTempC();
    doc["humidity1"] = bme1.readHumidity();
    doc["pressure1"] = bme1.readPressure();
  } else message_to_esp("BME sensor 1 not detected");

  if (bme2.init() == 0x60)
  {
    doc["temperature2"] = bme2.readTempC();
    doc["humidity2"] = bme2.readHumidity();
    doc["pressure2"] = bme2.readPressure();
  } else message_to_esp("BME sensor 2 not detected");

  doc["time"] = unix_time + (int)((currentTime()-time_last)/1000);

  if(pms_value_updated)
  {
    doc["pm01"] = pms.pm01;
    doc["pm10"] = pms.pm10;
    doc["pm25"] = pms.pm25;
    pms_value_updated = false;
  }

  // Write to document
  message_to_esp("BME280 measured");
  write_to_file(doc, "data.txt");
  write_to_file(doc, "today.txt");
}

void s2_measure_PMS()
{
  // Power on pms sensor and refresh air
  pms.init();
  pms.wake();
  sleep(32); 

  // Update values and global variables
  pms.read();
  pms.sleep();
  pms_value_updated = true;
  pms_last = currentTime();

  // Send message to esp
  message_to_esp("PMS5003 measured");
}

void s3_send()
{
  digitalWrite(INTERRUPT_OUTPUT_PIN, true);

  // If ESP ready to receive
  if(sleep_while(120))
  {
    if(SD.begin(6)){
    File file = SD.open("today.txt", FILE_READ);
    if(file)
    {
      while (true) 
      {
        // Create json object and buffer to write it to
        StaticJsonDocument<256> doc;
        char buffer[256];

        DeserializationError err = deserializeJson(doc, file);
        if (err) break;

        // Send message to ESP
        serializeJson(doc, buffer);
        Serial.println(buffer);
        delay(100);
      }
      file.close();
      SD.remove("today.txt");
    } else message_to_esp("error opening file");
  } else message_to_esp("SD couldn't initialize");
  SD.end();
  }
}

void s4_time()
{
  digitalWrite(INTERRUPT_OUTPUT_PIN, true);

  if(sleep_while(120))
  {
    // Obtain time
    Serial1.write('t');
    delay(100);
    String time_string = Serial1.readStringUntil('\n');
    message_to_esp("Time received by Arduino (str): " + String(unix_time));

    unsigned long recv_time = (unsigned long)time_string.toInt();
    unix_time = (recv_time > unix_time) ? recv_time : unix_time;
    
    // Print the received time
    message_to_esp("Time received by Arduino: " + String(unix_time));
  }
  digitalWrite(INTERRUPT_OUTPUT_PIN, false);
}

void s5_picture()
{
  digitalWrite(INTERRUPT_OUTPUT_PIN, true);

  if(sleep_while(120))
  {    
    Serial1.write('p');
    bool done = sleep_while(60);
  }
  //digitalWrite(INTERRUPT_OUTPUT_PIN, false);
}

void s6_video()
{
  digitalWrite(INTERRUPT_OUTPUT_PIN, true);

  if(sleep_while(120))
  {    
    Serial1.write('v');
    bool done = sleep_while(60);
  }
  //digitalWrite(INTERRUPT_OUTPUT_PIN, false);
}


//=======================================//
//=========== Transitions ===============//
//=======================================//


bool transitionS0S1()
{
  bool check = (currentTime() - bme_last >= bme_interval) ? true : false;
  return check;
}

bool transitionS0S2()
{
  bool check = (currentTime() - pms_last >= pms_interval) ? true : false;
  return check;
}

bool transitionS0S3()
{
  bool check = (currentTime() - send_last >= send_interval) ? true : false;
  return check;
}

bool transitionS0S4()
{
  bool check = (unix_time == 0) ? true : false;
  return check;
}

bool transitionS0S5()
{
  bool check = (currentTime() - picture_last >= pic_interval) ? false : false;
  return check;
}

bool transitionS0S6()
{
  if (currentTime() - video_last < cooldown || (currentTime() / 3600) % 24 + 1 < 7 || (currentTime() / 3600) % 24 + 1 > 21) return false;
  
  bool check = (digitalRead(PIR_PIN) == true) ? false : false;
  return check;
}

bool transitionS1S0(){return true;}
bool transitionS2S0(){return true;}
bool transitionS3S0(){return true;}
bool transitionS4S0(){return true;}
bool transitionS5S4(){return true;}
bool transitionS6S4(){return true;}


//=======================================//
//=========== Other functions ===========//
//=======================================//


// Write json message to file
void write_to_file(StaticJsonDocument<256> document, String filename)
{
  if(!SD.begin(6))
  {
    message_to_esp("SD couldn't initialize");
    return;
  }

  SD.begin(6);
  File myfile = SD.open(filename, FILE_WRITE); // Name should respect 8.3 limit
  if(myfile)
  {
    serializeJson(document, myfile);
    myfile.println();
    myfile.close();

    message_to_esp("written to file");
    bme_last = currentTime();
  } else message_to_esp("error opening file");
  SD.end();
}

// Sleep sleep_time seconds
void sleep(int sleep_time)
{ 
  for(int i = 0; i < sleep_time; i++)  {sleep_cpu();}
}

// Sleep sleep_time seconds while ESP32 is not ready
bool sleep_while(int sleep_time)
{
  for(int i = 0; i < sleep_time; i++){
    myTimer += (millis() - timer_last);
    sleep_cpu();
    myTimer += 1024;
    timer_last = millis();
    
    if(Serial1.availableForWrite()) Serial1.write('?');
    delay(50);
    if(Serial1.read() == 'y') return true;
  }
  return false;
}


// Send
void message_to_esp(String message_string)
{
  digitalWrite(INTERRUPT_OUTPUT_PIN, true);
  delay(1000);
  if(true)//Serial.available())
  {
    Serial1.write("m");
    delay(20);
    Serial1.print(message_string);
    Serial.println(message_string);
    Serial1.write("\n");
  }
  digitalWrite(INTERRUPT_OUTPUT_PIN, false);
  delay(100);
}

//=======================================

void setup() 
{
  // Serial communication
  Serial.begin(115200, SERIAL_8N1);
  Serial1.begin(115200, SERIAL_8N1);
  Serial.setTimeout(1000);

  // Set pinModes
  pinMode(INTERRUPT_OUTPUT_PIN, OUTPUT);
  pinMode(PIR_PIN, OUTPUT);
  digitalWrite(INTERRUPT_OUTPUT_PIN, true);

  // Initialize BME280 sensor
  bme1.parameter.communication = 0;                    //I2C communication for Sensor 1 (bme1)
  bme2.parameter.communication = 0;                    //I2C communication for Sensor 2 (bme2)
  bme1.parameter.I2CAddress = 0x77;                    //I2C Address for Sensor 1 (bme1)
  bme2.parameter.I2CAddress = 0x76;                    //I2C Address for Sensor 2 (bme2)
  bme1.parameter.sensorMode = 0b01;                    //Setup Sensor mode for Sensor 1
  bme2.parameter.sensorMode = 0b01;                    //Setup Sensor mode for Sensor 2 
  bme1.parameter.IIRfilter = 0b100;                    //IIR Filter for Sensor 1
  bme2.parameter.IIRfilter = 0b100;                    //IIR Filter for Sensor 2
  bme1.parameter.humidOversampling = 0b101;            //Humidity Oversampling for Sensor 1
  bme2.parameter.humidOversampling = 0b101;            //Humidity Oversampling for Sensor 2
  bme1.parameter.tempOversampling = 0b101;             //Temperature Oversampling for Sensor 1
  bme2.parameter.tempOversampling = 0b101;             //Temperature Oversampling for Sensor 2
  bme1.parameter.pressOversampling = 0b101;            //Pressure Oversampling for Sensor 1
  bme2.parameter.pressOversampling = 0b101;            //Pressure Oversampling for Sensor 2
 
  // Initialize PMS5003 sensor
  pms.init();
  pms.sleep();

  // Define state transitions
  S0->addTransition(&transitionS0S1,S1);
  S0->addTransition(&transitionS0S2,S2);
  S0->addTransition(&transitionS0S3,S3);
  S0->addTransition(&transitionS0S4,S4);
  S0->addTransition(&transitionS0S5,S5);
  S0->addTransition(&transitionS0S6,S6);
  S1->addTransition(&transitionS1S0,S0);
  S2->addTransition(&transitionS2S0,S0);
  S3->addTransition(&transitionS3S0,S0);
  S4->addTransition(&transitionS4S0,S0);
  S5->addTransition(&transitionS5S4,S4);
  S6->addTransition(&transitionS6S4,S4);
 
  // Initialize sleep mode
  RTC_init();   
  set_sleep_mode(SLEEP_MODE_PWR_DOWN);  // Set sleep mode to POWER DOWN mode 
  sleep_enable(); 

  // Wait for ESP to initialize and send message
  sleep_while(120);
  message_to_esp("Arduino initialized");
  digitalWrite(INTERRUPT_OUTPUT_PIN, false);
}

void loop() 
{
  machine.run();
  delay(10);
}
//*/

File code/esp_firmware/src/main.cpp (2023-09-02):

/*  esp_firmware/src/main.cpp  -   Main code designed to run on LilyGo ESP32

    This code consists of five main functions:
    - void init_modem() initializes the modem by calling modem_on() repeatedly until the modem powers on, and 
    subsequently acquires and prints modem information;
    - void connect() is used to connect the device to MQTT over 4G connection by calling connectGPRS() and connectMQTT();
    - void init_camera() initializes the camera using pins and variables as defined in the camera_config structure;
    - void take_picture() is used to take a picture and send it in JPEG format to the MQTT broker. As a result, 
    pictures taken in other formats are converted to JPEG first;
    - void sendCurrentTime() obtains the current timestamp and sends it to the Arduino Every.

    In void setup() the functions init_modem(), init_camera(), and connect() are called, in order to initialize modem and camera and 
    properly connect the device to internet. The functions that are called in void loop() are determined by the Arduino input and processed
    using a switch-case structure. The following Arduino input is possible:
    - '?' requests the state of the ESP32, which will respond with 'y' if connected. Otherwise connect() is called;
    - 't' calls sendCurrentTime() in order to communicate the current timestamp to Arduino;
    - 's' reads an incoming json message from Arduino and publishes it to MQTT;
    - 'm' is used for debugging purposes only and prints messages from Arduino to the Serial Monitor.;
    - 'p' calls take_picture() once and sends a JPG image to MQTT;
    - 'v' calls take_picture() repeatedly to send a series of JPG images to MQTT, which get merged to a MP4 clip on the server side.

    Note that the ESP32 default state is to be shut down. Only if the Arduino opens the FET, the ESP32 will get battery power.

*/

#include <Arduino.h>
#include <WiFi.h>
#include <ArduinoJson.h>
#include <StreamUtils.h>
#include "time.h"

// SIM model
#define TINY_GSM_MODEM_SIM7600

// Set serial for debug console, AT commands and debug prints
#define Serial Serial
#define SerialAT Serial1
#define TINY_GSM_DEBUG Serial

// Set TinyGsm en MQTT
#include <TinyGsmClient.h>
#include <PubSubClient.h>
TinyGsm modem(SerialAT);
TinyGsmClient client(modem);
PubSubClient mqtt(client);

// set GSM PIN and apn details
#define GSM_PIN "0000"

const char* apn = "m2m.tele2.com";
const char* gprsUser = "";
const char* gprsPass = "";

// MQTT details
const char* broker = "excellent-engraver.cloudmqtt.com";        // Public IP address or domain name
const char* mqttUsername = "fnrfeqot";                          // MQTT username
const char* mqttPassword = "P-1Ta8Utd1Pj";                      // MQTT password
const char* topicMeasure = "device/6/measurement";              // Topic measurement
const char* topicRecord = "device/6/rec";                       // Topic start recording
const char* topicImage = "device/6/img";                        // Topic image
const char* topicClip = "device/6/clip";                        // Topic clip

// Modem pins
#define uS_TO_S_FACTOR          1000000ULL  // Conversion factor for micro seconds to seconds
#define TIME_TO_SLEEP           60          // Time ESP32 will go to sleep (in seconds) 
#define PIN_TX                  27
#define PIN_RX                  26
#define UART_BAUD               115200
#define PWR_PIN                 4
#define LED_PIN                 12
#define POWER_PIN               25

bool reply = false;
uint32_t lastReconnectAttempt = 0;
size_t cnv_buf_len;
uint8_t * cnv_buf = NULL;

// Camera related
#include "esp_camera.h"
#include "soc/soc.h"           // Disable brownout problems
#include "soc/rtc_cntl_reg.h"  // Disable brownout problems
#include "driver/rtc_io.h"


// Camera model
#define CAMERA_MODEL_AI_THINKER_MODIFIED

// Pin definition for camera models
#if defined(CAMERA_MODEL_AI_THINKER)
  #define PWDN_GPIO_NUM     32
  #define RESET_GPIO_NUM    -1
  #define XCLK_GPIO_NUM      0
  #define SIOD_GPIO_NUM     26
  #define SIOC_GPIO_NUM     27

  #define Y9_GPIO_NUM       35
  #define Y8_GPIO_NUM       34
  #define Y7_GPIO_NUM       39
  #define Y6_GPIO_NUM       36
  #define Y5_GPIO_NUM       21
  #define Y4_GPIO_NUM       19
  #define Y3_GPIO_NUM       18
  #define Y2_GPIO_NUM        5
  #define VSYNC_GPIO_NUM    25
  #define HREF_GPIO_NUM     23
  #define PCLK_GPIO_NUM     22

#elif defined(CAMERA_MODEL_AI_THINKER_MODIFIED)
  #define PWDN_GPIO_NUM     32
  #define RESET_GPIO_NUM    -1
  #define XCLK_GPIO_NUM      0
  #define SIOD_GPIO_NUM     21
  #define SIOC_GPIO_NUM     22

  #define Y9_GPIO_NUM       33
  #define Y8_GPIO_NUM       34
  #define Y7_GPIO_NUM       13
  #define Y6_GPIO_NUM       15
  #define Y5_GPIO_NUM       5
  #define Y4_GPIO_NUM       19
  #define Y3_GPIO_NUM       39
  #define Y2_GPIO_NUM       36 
  #define VSYNC_GPIO_NUM    18
  #define HREF_GPIO_NUM     23
  #define PCLK_GPIO_NUM     12

#else
  #error "Camera model not selected"
#endif

// Time parameters
const char* ntpServer = "pool.ntp.org";
const long  gmtOffset_sec = 0;
const int   daylightOffset_sec = 3600;
unsigned long lastMillis = 0;

// Structure containing all camera pins and variables
static camera_config_t camera_config = {
    .pin_pwdn = PWDN_GPIO_NUM,
    .pin_reset = RESET_GPIO_NUM,
    .pin_xclk = XCLK_GPIO_NUM,
    .pin_sccb_sda = SIOD_GPIO_NUM,
    .pin_sccb_scl = SIOC_GPIO_NUM,
    .pin_d7 = Y9_GPIO_NUM,
    .pin_d6 = Y8_GPIO_NUM,
    .pin_d5 = Y7_GPIO_NUM,
    .pin_d4 = Y6_GPIO_NUM,
    .pin_d3 = Y5_GPIO_NUM,
    .pin_d2 = Y4_GPIO_NUM,
    .pin_d1 = Y3_GPIO_NUM,
    .pin_d0 = Y2_GPIO_NUM,
    .pin_vsync = VSYNC_GPIO_NUM,
    .pin_href = HREF_GPIO_NUM,
    .pin_pclk = PCLK_GPIO_NUM,

    .xclk_freq_hz = 12000000,
    .ledc_timer = LEDC_TIMER_0,
    .ledc_channel = LEDC_CHANNEL_0,
    .pixel_format = PIXFORMAT_JPEG,
    .frame_size = FRAMESIZE_QCIF,
    .jpeg_quality = 50,
    .fb_count = 1,
    .grab_mode = CAMERA_GRAB_LATEST //CAMERA_GRAB_WHEN_EMPTY
};

// Power on SIM7600 modem
void modem_on()
{   
    // The time of active low level impulse of PWRKEY pin to power on module, typically 500 ms
    Serial.println("\nStarting Up Modem...");
    digitalWrite(LED_PIN, LOW);   
    digitalWrite(POWER_PIN, HIGH);
    digitalWrite(PWR_PIN, HIGH);
    delay(500);
    digitalWrite(PWR_PIN, LOW);
    delay(5000);
    
    // Test modem response
    Serial.println("\nTesting Modem Response...\n");
    Serial.println("****");
    for(int i=0; i < 10; i++){
        SerialAT.println("AT");
        delay(500);
        if (SerialAT.available()) {
            String r = SerialAT.readString();
            Serial.println(r);
            if ( r.indexOf("OK") >= 0 ) {
                reply = true;
                break;
            }
        }
        delay(500);
    }
    Serial.println("****\n");
}
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

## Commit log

2022-03-06 got powerdown working reliably!
2022-03-19 fixed time, and added testing camera code
    [main.cpp]
2022-04-23 KiCad project
    [ESP_arduino.sch, Power_supply.sch, vogelhuisje_kicad.kicad_pcb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]
2022-04-23 Update ESP_arduino.sch-bak, Power_supply.sch, and 25 more files...
    [Power_supply.sch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]
2022-04-23 Update ESP_arduino.sch, Power_supply.sch, and 5 more files...
    [ESP_arduino.sch, Power_supply.sch, vogelhuisje_kicad.sch]
2022-04-28 Add Camera to schematic
    [Camera_module.sch, ESP_arduino.sch, Power_supply.sch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]
2022-04-29 Update Camera_module.sch, Camera_module.sch-bak, and 5 more files...
    [Camera_module.sch, ESP_arduino.sch, vogelhuisje_kicad.sch]
2022-06-25 PCB design
    [Camera_module.kicad_sch, ESP_arduino.kicad_sch, Power_supply.kicad_sch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]
2022-07-04 PCB done with version 1
    [ESP_arduino.kicad_sch, Power_supply.kicad_sch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]
2022-07-04 fixed gerber file export
    [vogelhuisje_camera_board-B_Mask.gbs, vogelhuisje_camera_board-B_Paste.gbr, vogelhuisje_camera_board-B_Silkscreen.gbo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]
2022-07-04 saved file
    [vogelhuisje_camera_board.kicad_pcb]
2022-11-13 Kicad Changes Tadjiro
    Board now supports 3 lipo cells and a motion sensor.
    [Camera_module.kicad_sch, ESP_arduino.kicad_sch, Power_supply.kicad_sch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]
2022-12-06 1st prototype
2022-12-28 camera test code
2023-01-04 Updated Camera Board
    Moved capacitors close to LDO output, corrected capacitor values and ported ground from the main board.
    [Camera_module.kicad_sch, vogelhuisje_camera_board.kicad_pcb, vogelhuisje_camera_board.kicad_sch]
2023-01-04 Update main board
    Ground port added to connector
    [vogelhuisje_kicad.kicad_pcb, vogelhuisje_kicad.kicad_sch]
2023-01-28 Update arduino_firmware
2023-02-03 Old changes reuploaded
    Weird thing happened with git pushes. Hopefully this will solve the problems
    [Camera_module.kicad_sch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]
2023-02-03 Gevecht met gerbers
    The gerber files put up a fight but at the end of the day I was able to make them work.
    [vogelhuisje_camera_board-B_Mask.gbs, vogelhuisje_camera_board-B_Silkscreen.gbo, vogelhuisje_camera_board-Back.gbl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]
2023-02-17 changed camera connector, and updated regulator pins
    [vogelhuisje_camera_board-NPTH-drl_map.dxf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]
2023-02-17 forgot to save
    [Camera_module.kicad_sch, vogelhuisje_camera_board.kicad_sch]
2023-02-24 updated to use new connector footprint
    [Camera_module.kicad_sch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]
2023-03-10 Camera seems to be working now. MQTT doesn't.
    [main.cpp]
2023-08-28 Pin reassignment
2023-09-01 Structure change
    File structure change to cleanup KiCad Files
    [Camera_module.kicad_sch, Camera_module.sch, ESP_arduino.kicad_sch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]
2023-11-30 Github fixen, update vandaag
    [Cameraconfig.cpp, Cameraconfig.h, http2.cpp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]
2023-12-01 Added printstatements, added files *_lib
    Print statements to find errors
    Added extra *_lib files doing the same thing as inspiration
    Right now the request fails after sending a few chuncks (usually 3)
    [Cameraconfig.cpp, Cameraconfig.h, http_wifi.cpp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]
2024-04-28 Push Simplified
    [Birdhouse2.kicad_pcb, Birdhouse2.kicad_sch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]
2024-05-01 Finish pcb simplified
    [CamMotion.kicad_pcb, CamMotion.kicad_sch, ESP_arduino.kicad_sch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]
2024-05-05 Finished PCB
    Now more properly routed
    [CamMotion.kicad_pcb, ESP_arduino.kicad_sch, Power_supply.kicad_sch]
